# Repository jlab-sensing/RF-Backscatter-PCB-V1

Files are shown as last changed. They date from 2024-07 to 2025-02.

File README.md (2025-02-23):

# WaDAR Tag V1

This repo consists of the backscatter tag PCBs used with the WaDAR sensing system. This repo is a submodule of [WaDAR](https://github.com/jlab-sensing/wadar). This is our first version of the tag used in WaDAR's sensing system.

## Versions Overview

Each version is archived upon PCB fabrication and assembly, ensuring traceability and reproducibility of hardware iterations.

### WaDAR_Tag_V1_0
- **Status**: Archived (Non-functional)
- **Description**: Initial prototype of backscatter tag PCB. Board is included for historical refernce; does not support functional operation.
- **Authors**: Josie Dominguez, jocadomi@ucsc.edu

### WaDAR_Tag_V1_1
- **Description**: First operational version of the backscatter tag. Oscillates at a fixed frequency of 2^n Hz, where n is determined by the selected oscillator. 
- **Authors**: Eric Vetha, evetha@ucsc.edu | Jack Lin, jlin143@ucsc.edu

### WaDAR_Tag_V1_2 
- **Description**: Enhanced version featuring an oscillator supporting a more flexible frequency range.
- **Authors**: Eric Vetha, evetha@ucsc.edu

---

>This README will be updated as more information becomes available.

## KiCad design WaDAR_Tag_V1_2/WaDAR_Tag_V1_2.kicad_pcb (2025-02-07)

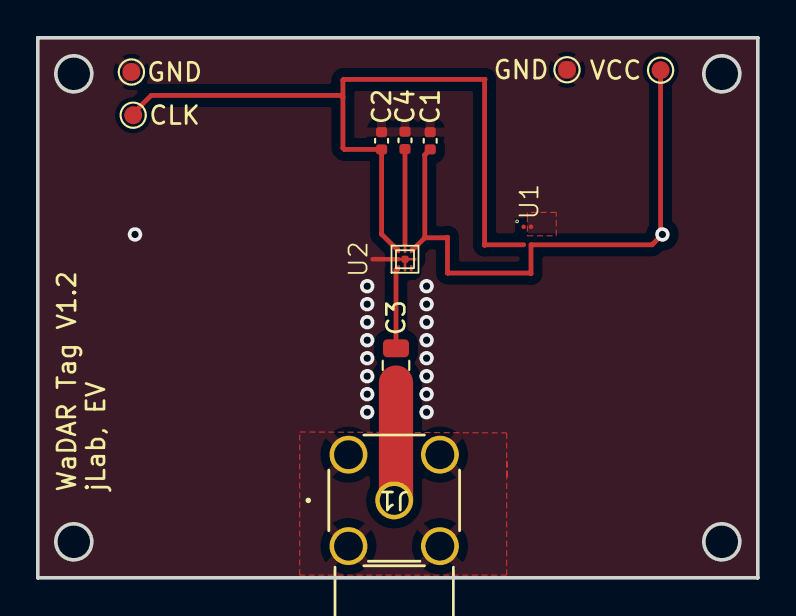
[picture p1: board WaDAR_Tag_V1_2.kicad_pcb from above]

Board: 2 copper layers, 40.0 x 30.0 mm, 12 parts (1 on the bottom side), 6 nets.

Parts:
BT1: 1060; BatteryHolder_Keystone_1060_1x2032
C1, C2: CAP CER 33PF 0402; C_0402_1005Metric
C3: CAP CER 100PF 0805; C_0805_2012Metric
C4: CAP CER 100PF 0402; C_0402_1005Metric
CLK: CLK; TestPoint_Pad_D1.0mm
GND: GND; TestPoint_Pad_D1.0mm
GND#2: GND; TestPoint_Pad_D1.0mm
J1: 142-0701-321; CONN_SMA-J-P-H-RA-TH1_SAI
U1: SIT1569AC-J3-30E-0000.080000; SiT1569
U2: SKY13351-378LF; SKY13351_FP
VCC: VCC; TestPoint_Pad_D1.0mm

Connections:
GND: BT1.2 (-), C1.2, C2.2, C4.2, GND.1, GND#2.1, J1.2, J1.3, J1.4, J1.5, U1.4 (GND), U2.2 (GND)
unnamed: BT1.1 (+), C1.1, U1.3 (Vdd), U2.4 (VCTL2), VCC.1
unnamed: C3.2, J1.1
unnamed: C2.1, CLK.1, U1.2 (CLK_Out), U2.6 (VCTL1)
unnamed: C4.1, U2.5 (INPUT)
unnamed: C3.1, U2.1 (OUTPUT1)

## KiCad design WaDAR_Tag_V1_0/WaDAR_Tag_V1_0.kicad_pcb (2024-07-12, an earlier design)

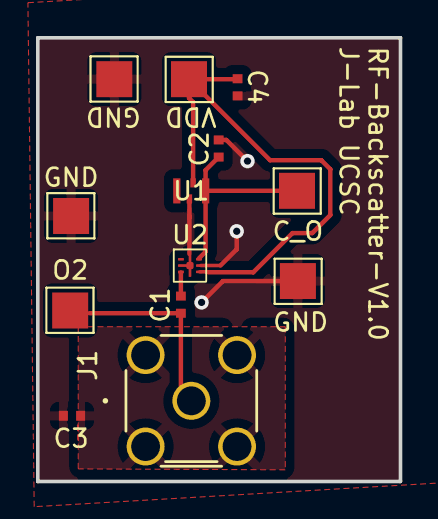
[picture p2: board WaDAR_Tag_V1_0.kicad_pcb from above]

Board: 2 copper layers, 20.2 x 24.7 mm, 13 parts (0 on the bottom side), 6 nets.

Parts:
C1, C3: CBR04C101J3GAC; CAPC10555_55N_KEM
C2, C4: GJM1555C1H330JB01D; CAPC10555_55N_KEM
C_O: CLK_OUT; EpicTestPointV1
GND: GND; EpicTestPointV1
GND#2, GND#3: GND; EpicTestPointV1
J1: SMA-J-P-H-RA-TH1; CONN_SMA-J-P-H-RA-TH1_SAI
O2: OUTPUT2; EpicTestPointV1
U1: SIT1534AI-H4-DCC-00.001E; XTAL4_SiT1533_SIT
U2: SKY13351_FP
VDD: VDD; EpicTestPointV1

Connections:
+1V8: C4.1, U1.4 (Vdd), U2.4 (VCTL2), VDD.1
GND: C2.2, C3.1, C4.2, GND.1, GND#2.1, GND#3.1, U1.2 (GND), U2.2 (GND), U2.5 (INPUT)
unnamed: C1.2, J1.1, O2.1
unnamed: C3.2, J1.2, J1.3, J1.4, J1.5
unnamed: C2.1, C_O.1, U1.3 (CLK_Out), U2.6 (VCTL1)
unnamed: C1.1, U2.3 (OUTPUT2)

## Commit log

2023-11-05 adding KiCAD project folder
    [RFBackscatterV1.kicad_pcb, RFBackscatterV1.kicad_sch]
2024-02-18 staging KiCAD files and new component library
2024-02-26 Added SiT1534
    [RFBackscatterV1.kicad_sch]
2024-02-26 Added BGSX33M5U16E6327XTSA1 and replaced low power oscillator
2024-07-05 Added SKY13351, finished initial schematic
    [RFBackscatterV1.kicad_sch, Sheet1.SchDoc]
2024-07-08 Finished SKY13351 footprint, staged board
    [RFBackscatterV1.kicad_pcb, RFBackscatterV1.kicad_sch]
2024-07-12 updated board, added buffer and filter capacitors
    [RFBackscatterV1.kicad_pcb]
2024-07-12 generated manufacturing files for V1.0
    [RFBackscatterV1-B_Cu.gbr, RFBackscatterV1-B_Mask.gbr, RFBackscatterV1-B_Paste.gbr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]
2024-12-05 fixed input pin capacitor and RF connector ground
    [RFBackscatterV1.kicad_pcb, RFBackscatterV1.kicad_sch]
2024-12-05 fixed design
    [MY-LR44-021_MY-LR44-02.schdoc, RFBackscatterV1.kicad_pcb]
2024-12-05 1.1 added coin cell
    [RFBackscatterV1.kicad_pcb, RFBackscatterV1.kicad_sch]
2024-12-07 alexandre's changes; schematic awaiting confirmation
    [RFBackscatterV1.kicad_sch]
2024-12-07 DNP R1
    [RFBackscatterV1.kicad_sch]
2024-12-08 PCB updated
    [RFBackscatterV1.kicad_pcb, RFBackscatterV1.kicad_sch]
2024-12-08 alexandre's advice pt2
    [RFBackscatterV1.kicad_pcb, RFBackscatterV1.kicad_sch]
2024-12-08 pre-board review
    [RFBackscatterV1.kicad_pcb, RFBackscatterV1.kicad_sch]
2024-12-30 pre board review 2
    [RFBackscatterV1.kicad_pcb, RFBackscatterV1.kicad_sch]
2025-01-09 JLPCB order
    [2025-01-08T170155.csv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]
2025-01-29 renamed project files
    [MY-LR44-021_MY-LR44-02.schdoc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]
2025-01-29 updated schematic with SiT1569
    [MY-LR44-021_MY-LR44-02.schdoc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]
2025-01-29 added footprint for SiT1549
    [WaDAR_Tag_V1_2.kicad_sch]
2025-02-02 added test points, made PCB double sided
    [WaDAR_Tag_V1_2.kicad_pcb, WaDAR_Tag_V1_2.kicad_sch]
2025-02-05 updated datasheets
    [WaDAR_Tag_V1_2.kicad_pcb, WaDAR_Tag_V1_2.kicad_sch]
2025-02-05 fixed all absolute pathing issues
    [MY-LR44-021_MY-LR44-02.schdoc, WaDAR_Tag_V1_2.kicad_pcb]
2025-02-05 added new RF junction
    [WaDAR_Tag_V1_2.kicad_sch]
2025-02-05 updated capacitors and added mounting holes
    [WaDAR_Tag_V1_2.kicad_pcb, WaDAR_Tag_V1_2.kicad_sch]
2025-02-07 V_2 off to assembly
    [RFBackscatterV1-B_Cu.gbl, RFBackscatterV1-B_Mask.gbs, RFBackscatterV1-B_Silkscreen.gbo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]
2025-02-23 fab files for V1_2
    [WaDAR_Tag_V1_2-NPTH.drl, WaDAR_Tag_V1_2-PTH.drl]
